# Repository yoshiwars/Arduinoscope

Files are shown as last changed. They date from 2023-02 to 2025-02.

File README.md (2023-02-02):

# Arduinoscope
My attempt to motorize my 8inch Dobsonian. Works fine with Stellarium. Motors are 27:1 Planetary Gearbox Nema 17s. Go to via bluetooth in Stellarium and object tracking is slightly off, probably because the gears and belts are not super high tolerance.

//TODO - Describe Parts List, Circuit diagrams, add photos, etc.

Relies on https://github.com/DavidArmstrong/SiderealPlanets for all the Alt/Az conversion

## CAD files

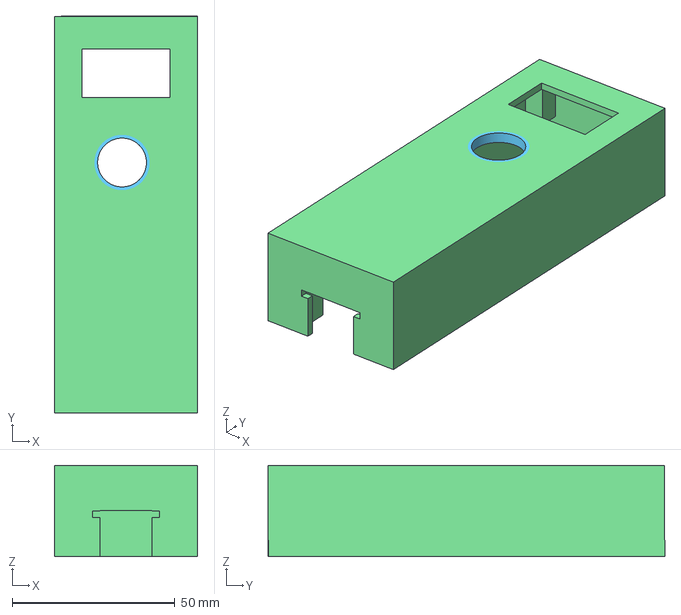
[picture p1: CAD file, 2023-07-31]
3D Print Files/Binoculurs/Handheld-Top.3mf
44.0 x 122.0 x 28.0 mm

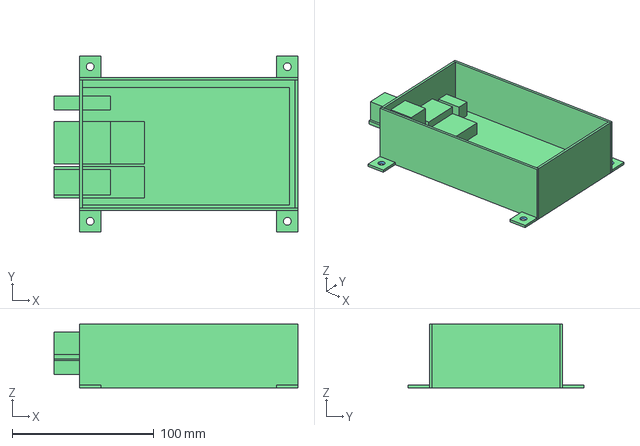
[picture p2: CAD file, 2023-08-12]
3D Print Files/Designs/Case for Telescope with focuser.3mf
172.0 x 124.0 x 45.0 mm

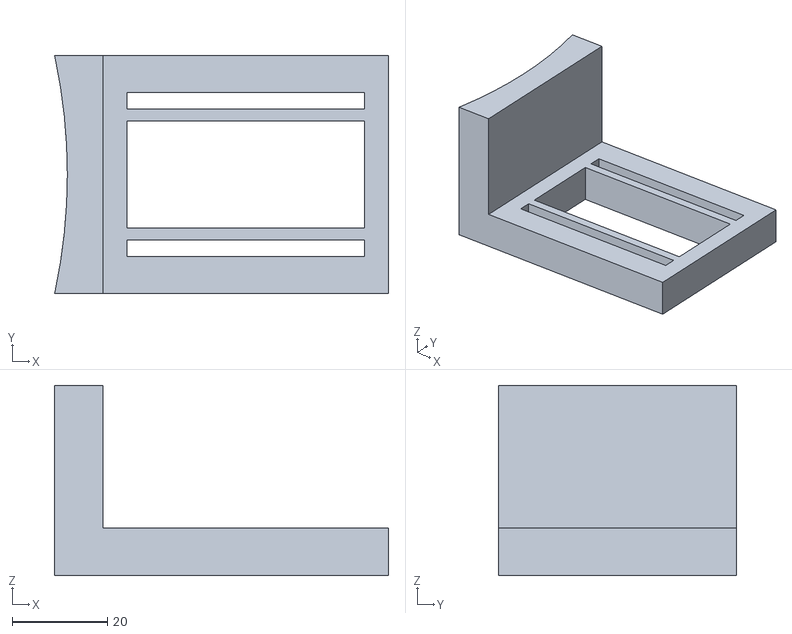
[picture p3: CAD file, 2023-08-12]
3D Print Files/STL/focuser mount.stl
70.2 x 50.0 x 40.0

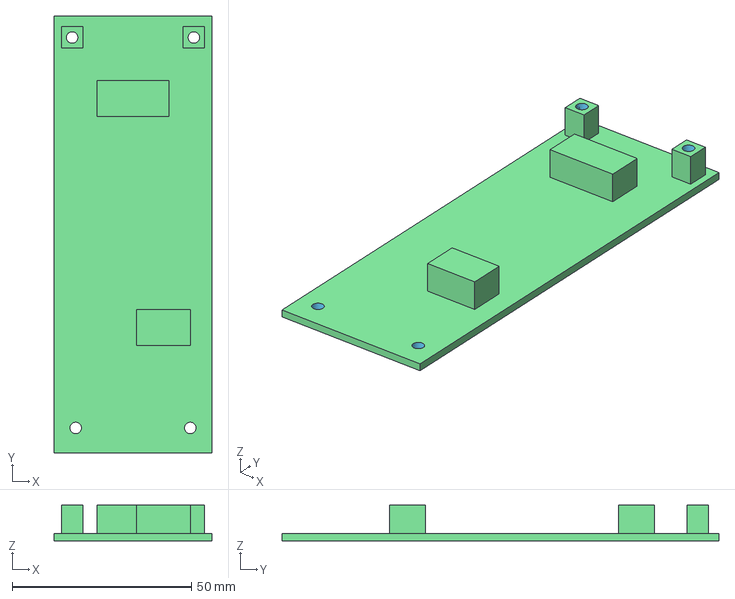
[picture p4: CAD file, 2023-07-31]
3D Print Files/Binoculurs/Handheld-Bottom.3mf
44.0 x 122.0 x 10.0 mm

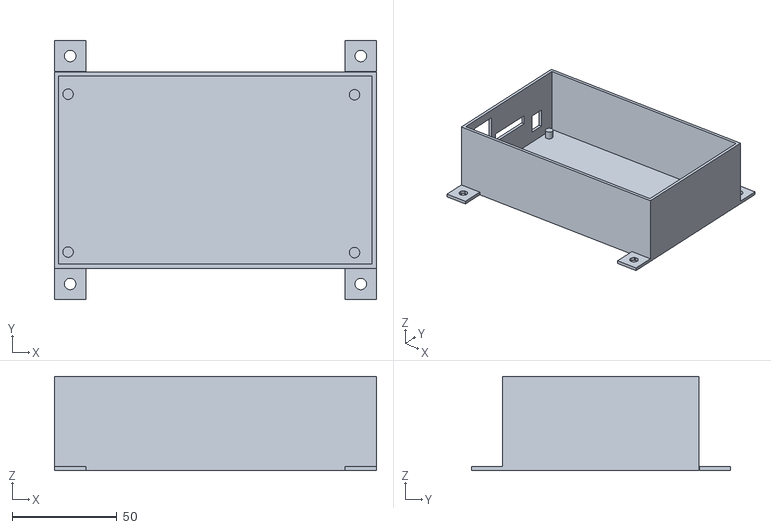
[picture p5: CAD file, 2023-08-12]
3D Print Files/STL/Case for Telescope with focuser.stl
154.0 x 124.0 x 45.0

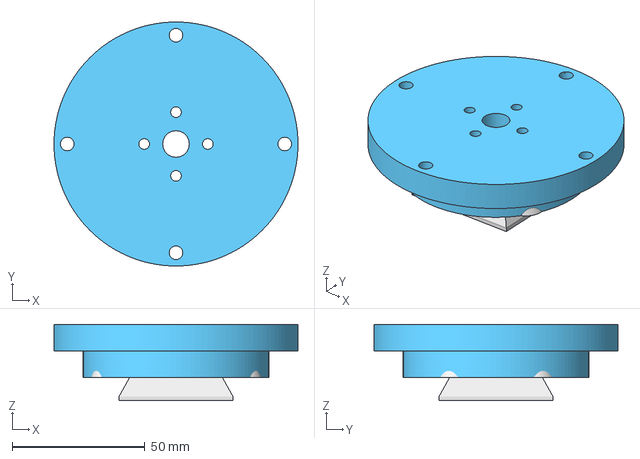
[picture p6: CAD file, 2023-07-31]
3D Print Files/Binoculurs/Bottom.3mf
92.0 x 92.0 x 28.7 mm

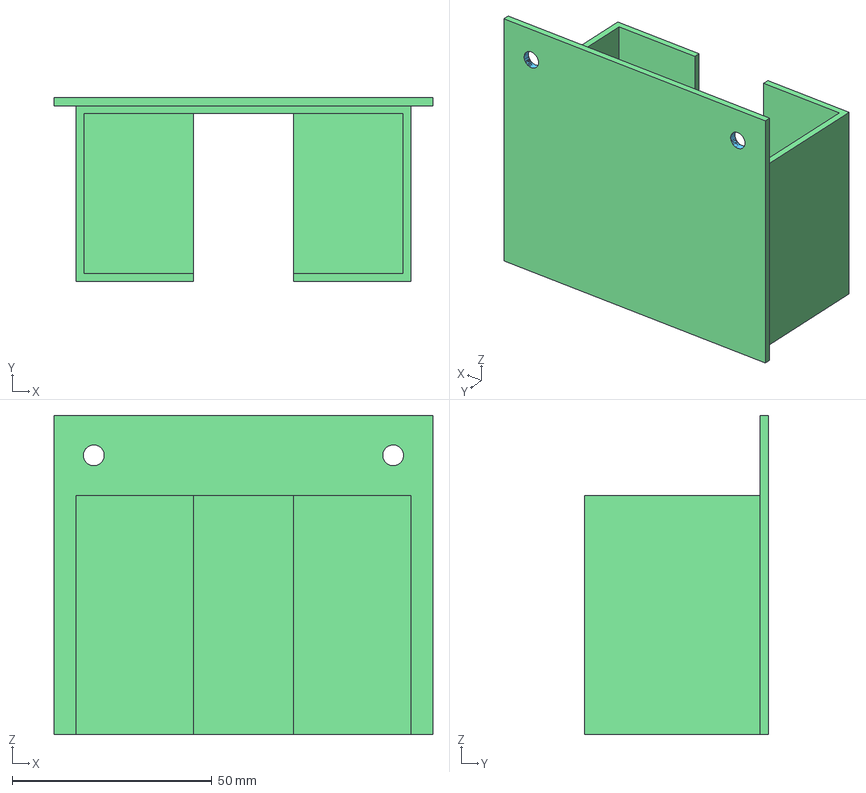
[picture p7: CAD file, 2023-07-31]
3D Print Files/Designs/BatteryHolder.3mf
95.0 x 46.0 x 80.0 mm

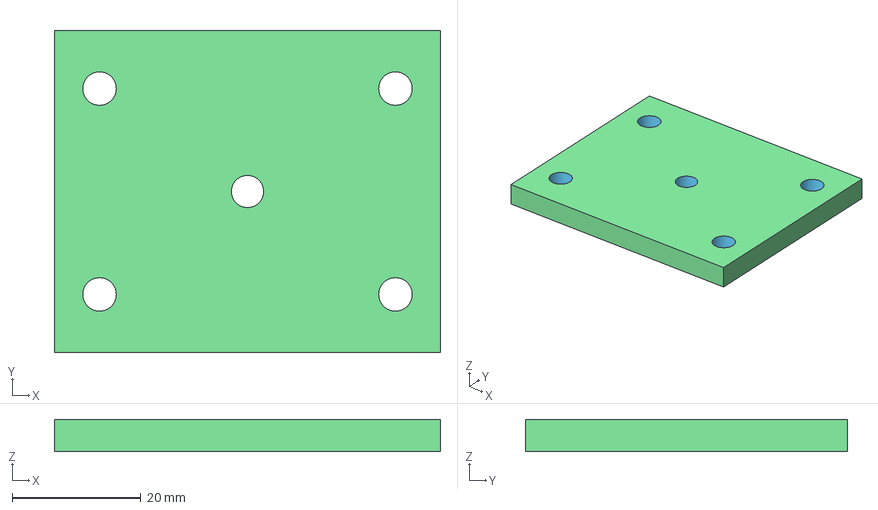
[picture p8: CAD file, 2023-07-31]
3D Print Files/Binoculurs/CameraMountPlate.3mf
60.0 x 50.0 x 5.00 mm

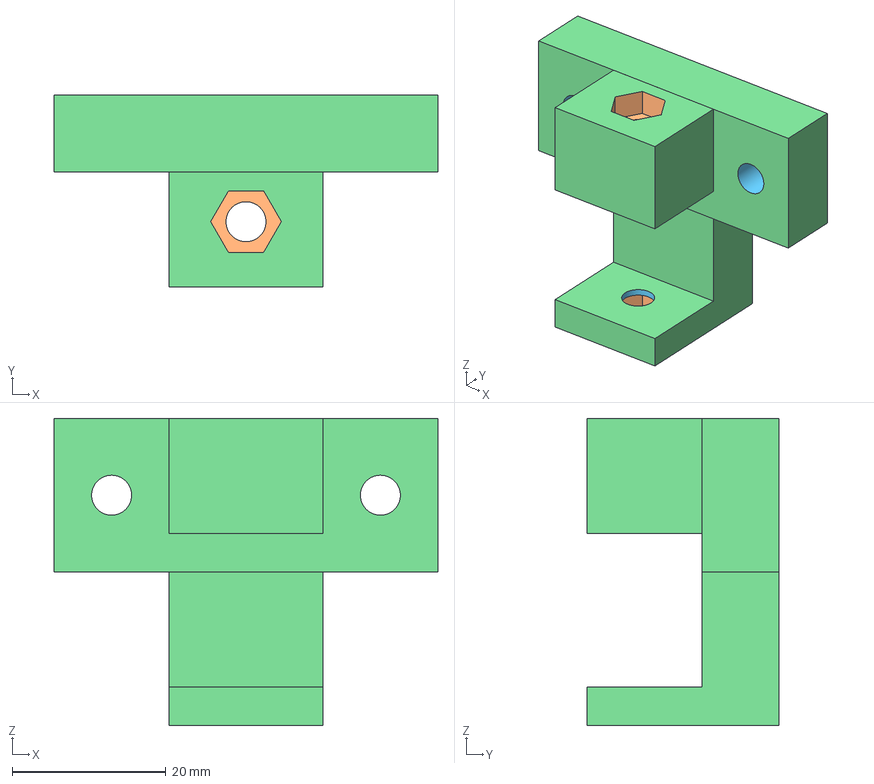
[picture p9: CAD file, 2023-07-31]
3D Print Files/Designs/Tensioner.3mf
50.0 x 25.0 x 40.0 mm

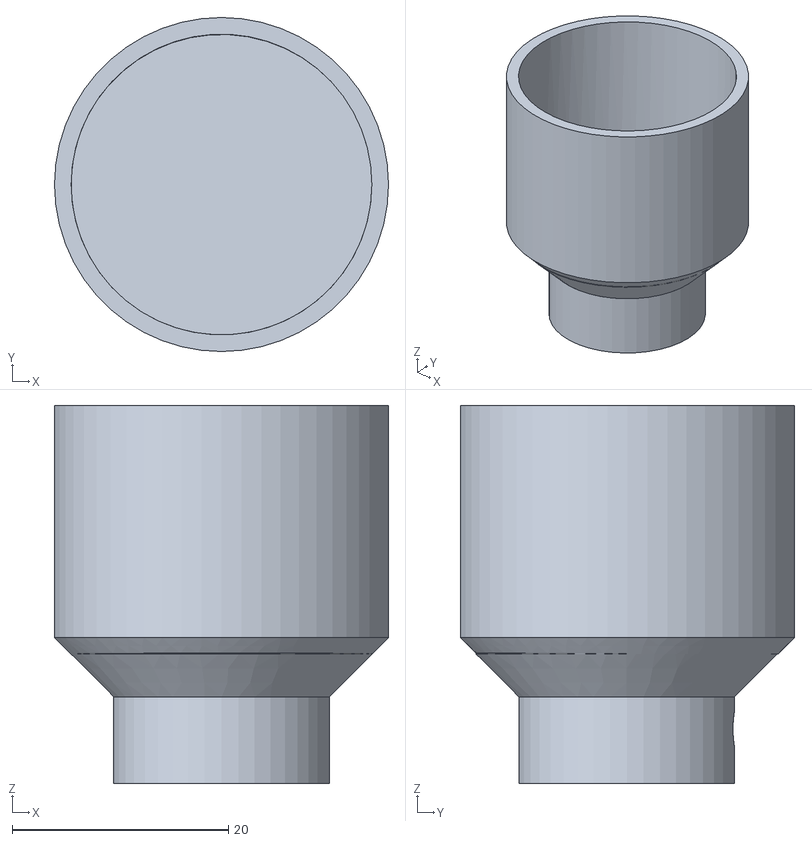
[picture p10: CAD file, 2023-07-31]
3D Print Files/STL/Focus socket-Cut002.stl
30.9 x 30.9 x 35.0

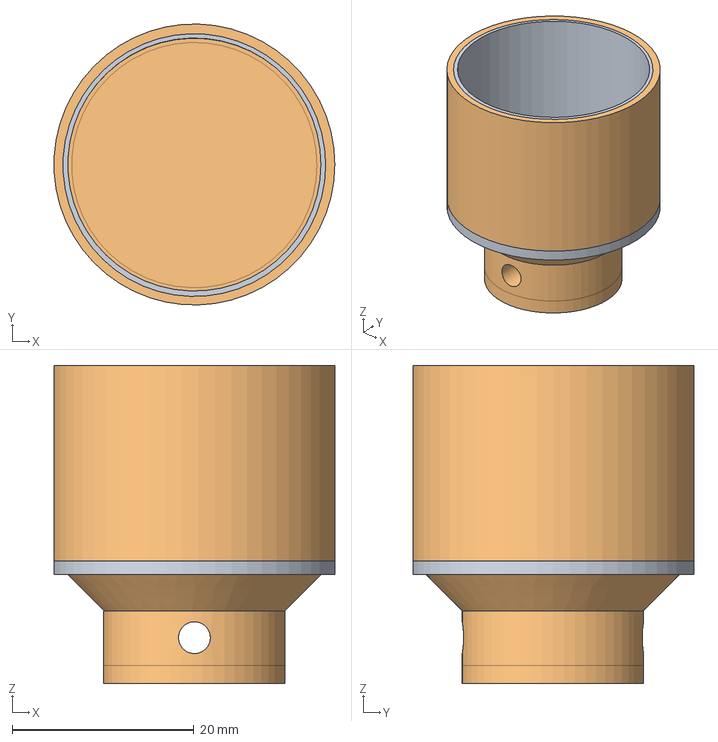
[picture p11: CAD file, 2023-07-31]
3D Print Files/Designs/Focus socket.FCStd
30.9 x 30.9 x 35.0 mm

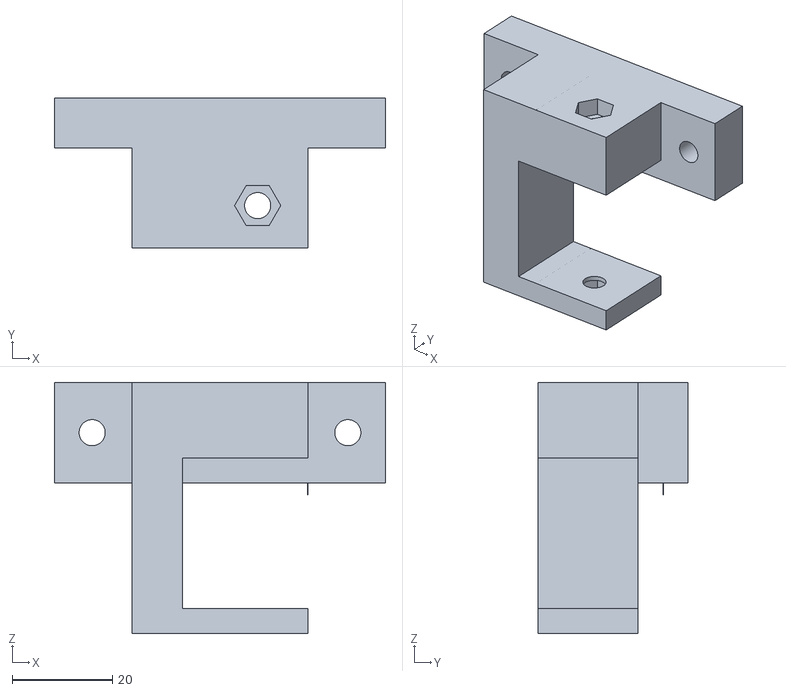
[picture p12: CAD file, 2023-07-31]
3D Print Files/STL/Tensioner.stl
65.9 x 30.0 x 50.0

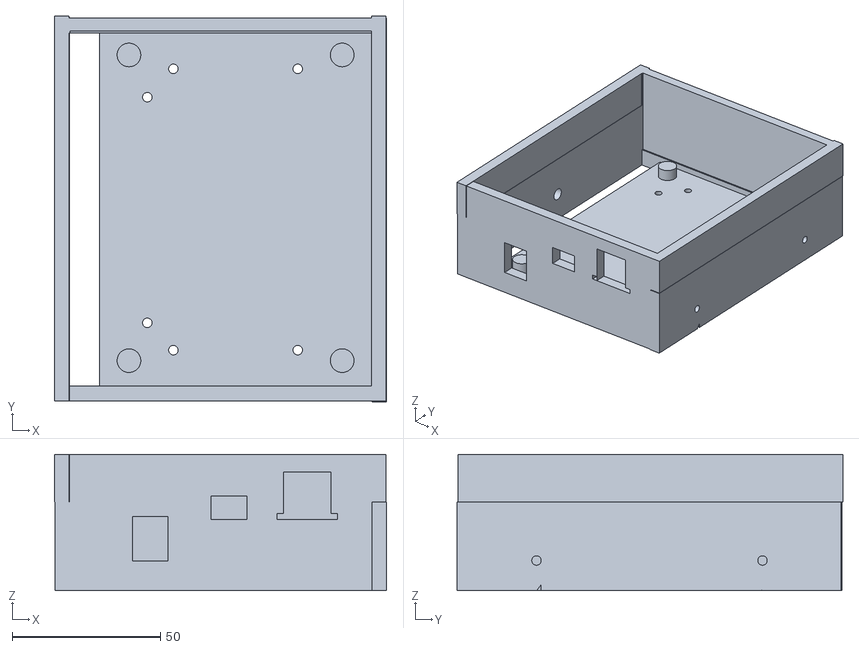
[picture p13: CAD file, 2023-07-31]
3D Print Files/Binoculurs/Motor and Board Holder.stl
112.2 x 130.3 x 46.0

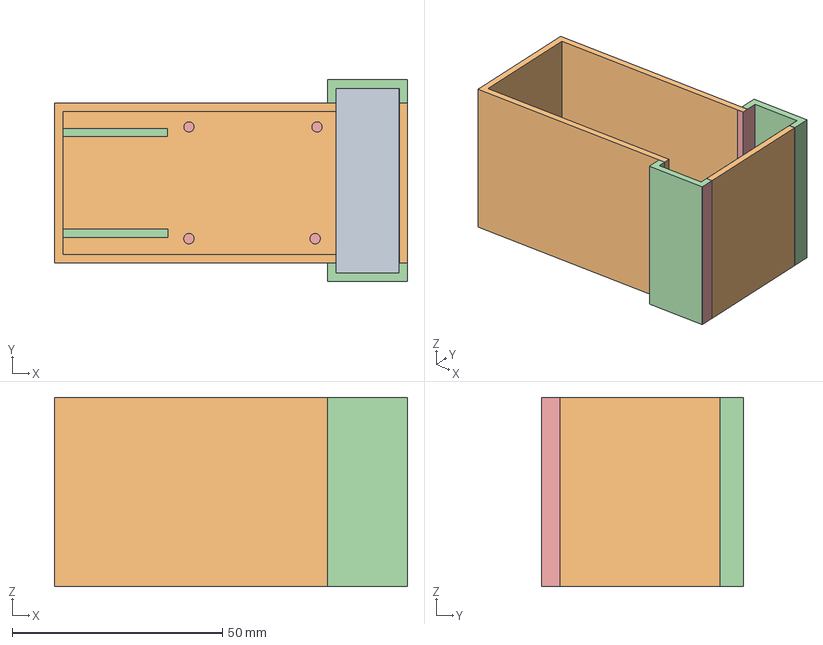
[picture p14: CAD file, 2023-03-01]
3D Print Files/Designs/MotorFocuser.FCStd
84.0 x 48.1 x 45.0 mm

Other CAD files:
3D Print Files/Designs/focuser mount.3mf
3D Print Files/STL/BatteryHolder.stl
3D Print Files/STL/Focus socket-Cut.stl
3D Print Files/Binoculurs/Box.stl
3D Print Files/Binoculurs/AxisSpacer.3mf
3D Print Files/Binoculurs/AxisSpacer.stl
3D Print Files/Binoculurs/AxisSpacerCut.stl
3D Print Files/Binoculurs/Bottom.stl
3D Print Files/Binoculurs/CameraMountPlate.stl
3D Print Files/Binoculurs/CameraMountSpacer.3mf
3D Print Files/Binoculurs/CameraMountSpacer.stl
3D Print Files/Binoculurs/Handheld-Bottom.stl
3D Print Files/Binoculurs/Handheld-Top.stl
3D Print Files/Binoculurs/Handheld.3mf
3D Print Files/Binoculurs/Motor and Board Bottom.3mf
3D Print Files/Binoculurs/Motor and Board Mount.3mf
3D Print Files/Binoculurs/Motor and Board Mount.stl
3D Print Files/Binoculurs/ScreenHolder.stl
3D Print Files/Binoculurs/StorageBox.3mf
3D Print Files/Binoculurs/StorageBox.stl
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

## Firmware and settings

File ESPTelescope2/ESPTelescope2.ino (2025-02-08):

#include "lcdgfx.h"
#include "lcdgfx_gui.h"
#include <AccelStepper.h>
#include <TinyGPSPlus.h>
#include <SiderealPlanets.h>
#include "BluetoothSerial.h"
#include <TimeLib.h>
#include "Preferences.h"
#include <SiderealObjects.h>
#include <ESP32Encoder.h>
#include <esp_now.h>
#include <WiFi.h>

/************************************************************************************************************************
Start Configurable Items 
*************************************************************************************************************************/
#define MOUNT_NAME "StarMax90"                    //Name of the Mount - Bluetooth Name etc.
#define FIRMWARE_VERSION "0.3"                     //Just for Informational Purposes
#define FIRMWARE_DATE "NOV 05 2024"                //Just for Informational Purposes
#define FIRMWARE_TIME "23:15:00"

//this is expecting the Alt and Az gearing to be the same. Will separate this at some point
const int GEAR_RATIO = 15;                       //where 1 is no gearing (ex. 300 Tooth gear / 20 tooth gear = 15), 15 Telescope, 1 Binoc
const double SINGLE_STEP_DEGREE =  360.0 / 200.0;    // the motor has 200 regular steps for 360 degrees (360 divided by 200 = 1.8)
const double MOTOR_GEAR_BOX = 26 + (103.0/121.0);                 //where 1 is no gearing (26 + (103/121)) planetary gearbox version
const float MAX_MOTOR_SPEED = 3000;              //250 is probably good without GEAR_RATIO >1, 1500 Telescope, 250 Binoc 

//Define Motor setup
const int ALT_DIRECTION_PIN = 13;                 //ALT Driver Dir
const int ALT_STEP_PIN = 12;                      //ALT Driver Step
const int AZ_DIRECTION_PIN = 27;                 //AZ Driver Dir
const int AZ_STEP_PIN = 14;                      //AZ Driver Step
const int MOTOR_INTERFACE_TYPE = 1;             //AccelStepper Motor Type 1
//#define MIN_PULSE_WIDTH 50                      //use to adjust stepper pulses, comment out for default

//Define Remote setup
const int Y_JOYSTICK_PIN = 35;                  //Up/Down Pin on the Remote
const int Y_INVERT = 1;                         //1 is normal, -1 inverted , binoc -1, telescope 1
const int X_JOYSTICK_PIN = 34;                  //Left/Right Pin on the remote
const int X_INVERT = 1;                        //1 is normal, -1 inverted , binoc -1, telescope 1

const int BUTTON_PIN = 39;                      //button on Remotes
const int ANALOG_READ_RESOLUTION = 4095;        //ESP32 has this resolution, other chips may vary

//Define Encoders
const int AZ_ENCODER_1 = 25;
const int AZ_ENCODER_2 = 26;
const double AZ_ENCODER_GEAR = 15;                //300 / 20
const double AZ_ENCODER_DEGREE_PER_STEP = 0.15;   //360 / (600 * 4)
const int AZ_ENCODER_INVERT = -1;                 //change the direction of the Encoder when adding to currentAz
const int ALT_ENCODER_1 = 32;
const int ALT_ENCODER_2 = 33;
const double ALT_ENCODER_GEAR = 15;               //300 / 20
const double ALT_ENCODER_DEGREE_PER_STEP = 0.15;  //360 / (600 * 4)
const int ALT_ENCODER_INVERT = -1;                //change the direction of the Encoder when adding to currentAlt
#define ENCODERFILTER                             //If moving too fast, need to lower the debounce to 0. Comment out at slower speeds.

//Comment Out HAS_FOCUSER for no Focuser
#define HAS_FOCUSER

#ifdef HAS_FOCUSER
  const int FOCUS_DIRECTION_PIN = 4;            //Focus Driver Dir
  const int FOCUS_STEP_PIN = 5;                 //Focus Driver Step
  const int MAX_FOCUS_SPEED = 1024;
  const int FOCUS_INTERFACE_TYPE = 1;           //1 is with driver DRV8825
#endif

//Shift Register for motor speeds
const int LATCH_PIN = 19;                       //Pin connected to ST_CP of 74HC595
const int CLOCK_PIN = 18;                       //Pin connected to SH_CP of 74HC595
const int DATA_PIN = 23;                         //Pin connected to DS of 74HC595

//Receiver
uint8_t receiverAddress[] = {0xa0, 0xb7, 0x65, 0x64, 0x29, 0x7c};


//uncomment to get debugging
//#define DEBUG
//#define DEBUG_STEPS
//#define DEBUG_X_JOYSTICK
//#define DEBUG_Y_JOYSTICK 
//#define DEBUG_GPS
//#define DEBUG_COMMS
//#define DEBUG_ENCODER
/************************************************************************************************************************
End Configurable Items
*************************************************************************************************************************/

/************************************************************************************************************************
Global Variables - These should not need to change based on devices
*************************************************************************************************************************/

BluetoothSerial btComm;       //Bluetooth Setup
SiderealPlanets myAstro;      //Used for calculations
SiderealObjects myObjects;    //Used for GoTo Functions
Preferences preferences;      //Stores persistent variables

//button states
int buttonState = LOW;                // the current reading from the input pin
int lastButtonState = LOW;            // the previous reading from the input pin
unsigned long lastDebounceTime = 0;   // the last time the output pin was toggled
unsigned long debounceDelay = 50;     // the debounce time; increase if the output flickers
unsigned long longPressTime = 500;
bool longYPressActive = false;
bool longXPressActive = false;

//AltAZ motor rotation min
const double rotationDegrees = (SINGLE_STEP_DEGREE / MOTOR_GEAR_BOX); //degrees / single step per rev / gearbox

//Motor Starts
AccelStepper yStepper = AccelStepper(MOTOR_INTERFACE_TYPE,ALT_STEP_PIN,ALT_DIRECTION_PIN);
AccelStepper xStepper = AccelStepper(MOTOR_INTERFACE_TYPE,AZ_STEP_PIN,AZ_DIRECTION_PIN);
#ifdef HAS_FOCUSER
AccelStepper focuser = AccelStepper(FOCUS_INTERFACE_TYPE,FOCUS_STEP_PIN,FOCUS_DIRECTION_PIN);
#endif


ESP32Encoder altEncoder;
ESP32Encoder azEncoder;


float xSpeed = 0;
float ySpeed = 0;
float fSpeed = 0;
float fSpeedSerial = MAX_FOCUS_SPEED;
float realXSpeed = 0;
float realYSpeed = 0;
float realFSpeed = 0;

int stepperSpeed = 3;
int lastStepperSpeed = 0;
int preTrackStepperSpeed = 3;
int stepperDivider = 1;

//Menu Control
unsigned int screenMode = 0;
/*
  0 - GPS Screen
  1 - Main Menu
  2 - Slew Mode
  3 - Settings Menu
  4 - Alignment Screen
      0 - Sync 1st Object
      1 - Sync 2nd Object
      2 - Sync 3rd Object
      3 - Confirm sync
  5 - Offsets Menu
  6 - Goto Menu
  7 - Planets Menu --Not in use anymore
  8 - Target Below Horizon
*/
unsigned int returnScreenMode = 0;
const char *mainMenuItems[] = 
{
  "Move:  Disabled",
  #ifdef HAS_FOCUSER
  "Focus: Disabled",
  #endif
  "Speed: Fast",
  "Settings",
  "Info",
  "GoTo"
};

unsigned int speedIndex = 1;

const char *settingsMenuItems[] = 
{
  "<-- Back",
  "Alignment",
  "Offsets",
  "Tracking: Enabled"
};

const char *alignmentMenuItems[] =
{
  "Move:  Disabled",
  "Speed: Fast",
  "Cancel Alignment"
};

const char *offSetsMenuItems[] =
{
  "<-- Back",
  "Alt:",
  "Az: ",
  "Reset to Default"
};

const char *gotoMenuItems[] =
{
  "<-- Back",
  "Planet: Mercury",
  "Messier: M1",
  "Caldwell: 1",
  "The Moon"
};

const char *planets[] =
{
  "Mercury",
  "Venus",
  "Mars",
  "Jupiter",
  "Saturn",
  "Uranus",
  "Neptune"
};

unsigned int messierObject = 1;
unsigned int caldwellObject = 1;
unsigned int planetObject = 0;

LcdGfxMenu mainMenu(mainMenuItems, sizeof(mainMenuItems) / sizeof(char *) );
LcdGfxMenu settingsMenu(settingsMenuItems, sizeof(settingsMenuItems) / sizeof(char *) );
LcdGfxMenu alignmentMenu(alignmentMenuItems, sizeof(alignmentMenuItems) / sizeof(char *) );
LcdGfxMenu offsetsMenu(offSetsMenuItems, sizeof(offSetsMenuItems) / sizeof(char *) );
LcdGfxYesNo alignmentConfirm("Apply new offset?");

LcdGfxMenu gotoMenu(gotoMenuItems, sizeof(gotoMenuItems)/sizeof(char *));

//alignment Variables
int alignmentScreen = 0;

//the following is to hold the incoming sync Alt and the current alt so that they can be compared.
double alignmentAltValues[][2] = {
  {0.0,0.0}, //sync Alt, current alt
  {0.0,0.0},
  {0.0,0.0}
};

double alignmentAzValues[][2] = {
  {0.0,0.0},
  {0.0,0.0},
  {0.0,0.0}
};

double alignmentAltOffset = 0.0;
double alignmentAzOffset = 0.0;

//JoyStick
int lastYState = 0;
int yState = 0;
unsigned long lastYDebounceTime = 0;
unsigned int yDeadZone = 0;
unsigned int xDeadZone = 0;
unsigned int maxY = ANALOG_READ_RESOLUTION;
unsigned int maxX = ANALOG_READ_RESOLUTION;

int lastXState = 0;
int xState = 0;
unsigned long lastXDebounceTime = 0;

bool moving = false;
bool yMoving = false;
bool xMoving = false;

bool focusing = false;

//communication
const byte numChars = 32;
char input[numChars];
char serialInput[numChars];
char output[numChars];
const byte gpsNumChars = 80;
char gpsData[gpsNumChars];
bool newData = false;
bool outData = false;
bool synced = false;


// Structure example to send data
// Must match the receiver structure
typedef struct struct_message {
  char message[numChars];  
} struct_message;

// Create a struct_message called myData
struct_message espNowOut;
struct_message espNowIn;

esp_now_peer_info_t peerInfo;

//Sync Time Variables
int inHourOffset;
int inHour;
int inMinute;
int inSecond;
int inMonth;
int inDay;
int inYear;


//GPS
TinyGPSPlus gps;
bool gpsAcquired = false;
long lastGPSCheck = 0;

float flat = 0;
float flon = 0;
float faltitude;

int sats;

float gpsQueryTime;

//hold the received RA, Dec
int raHH;
int raMM;
int raSS;
int decD;
int decMM;
int decSS;

//Sync coords
double currentAlt = 0;
double currentAz = 0;
double moveOffsets[] = {1.0,1.0};
double tempMoveOffsets[] = {1.0,1.0};

//Target Coords for slewing
int targetRaHH;
int targetRaMM;
int targetRaSS;
int targetDecD;
int targetDecMM;
int targetDecSS;
double targetAlt;
double targetAz;
bool slewComplete = true;
bool tracking = true;
bool isTracking = false;
long slewScreenTimeOut = 2000;
long slewScreenUpdate = 0;

const char *sites[4] = {"","","",""};

DisplaySSD1306_128x64_I2C display(-1); // or (-1,{busId, addr, scl, sda, frequency}). This line is suitable for most platforms by default

void setup() {
  preferences.begin("scope",false);   //start up preferences
  
  if(preferences.isKey("altOffset")){
    moveOffsets[0] = preferences.getDouble("altOffset");
  }

  if(preferences.isKey("azOffset")){
    moveOffsets[1] = preferences.getDouble("azOffset");
  }

  for(int i = 0; i < 4; i++){
    if(preferences.isKey("site" + i)){
      sites[i] = preferences.getString("site" + i).c_str();
    }
  }

  // Set device as a Wi-Fi Station
  WiFi.mode(WIFI_STA);

  // Init ESP-NOW
  if (esp_now_init() != ESP_OK) {
    Serial.println("Error initializing ESP-NOW");
    return;
  }

  // Once ESPNow is successfully Init, we will register for Send CB to
  // get the status of Trasnmitted packet
  esp_now_register_send_cb(OnDataSent);
  
  // Register peer
  memcpy(peerInfo.peer_addr, receiverAddress, 6);
  peerInfo.channel = 0;  
  peerInfo.encrypt = false;
  
  // Add peer        
  if (esp_now_add_peer(&peerInfo) != ESP_OK){
    Serial.println("Failed to add peer");
    return;
  }
  // Register for a callback function that will be called when data is received
  esp_now_register_recv_cb(esp_now_recv_cb_t(OnDataRecv));

  #ifdef HAS_FOCUSER
    speedIndex = 2;
  #endif
  // Set all Pin Modes
  pinMode(Y_JOYSTICK_PIN, INPUT);
  pinMode(X_JOYSTICK_PIN, INPUT);
  pinMode(BUTTON_PIN, INPUT_PULLUP);
  pinMode(LATCH_PIN, OUTPUT);
  pinMode(CLOCK_PIN, OUTPUT);
  pinMode(DATA_PIN, OUTPUT);
    
  //Start Comms
  #ifdef DEBUG
    Serial.begin(115200);   //USB
  #endif
  #ifndef DEBUG
    Serial.begin(9600);     //USB
  #endif


  //ESP32Encoder::useInternalWeakPullResistors = puType::down;
	// Enable the weak pull up resistors
	ESP32Encoder::useInternalWeakPullResistors = puType::up;

  altEncoder.attachFullQuad(ALT_ENCODER_1, ALT_ENCODER_2);
  azEncoder.attachFullQuad(AZ_ENCODER_1,AZ_ENCODER_2);

  #ifdef ENCODERFILTER
      altEncoder.setFilter(0);
      azEncoder.setFilter(0);
  #endif

  altEncoder.clearCount();
  azEncoder.clearCount();


  btComm.begin(MOUNT_NAME);   //Bluetooth
  Serial2.begin(9600);  //start GPS
  
  #ifdef DEBUG
    Serial.println("Start Up");
    Serial.print("Mount Name: ");
    Serial.println(MOUNT_NAME);
  #endif

  #ifdef MIN_PULSE_WIDTH
    xStepper.setMinPulseWidth(MIN_PULSE_WIDTH);
    yStepper.setMinPulseWidth(MIN_PULSE_WIDTH);
  #endif

  #ifdef DEBUG_STEPS
    Serial.print("GEAR_RATIO: ");
    Serial.println(GEAR_RATIO);
    Serial.print("SINGLE_STEP_DEGREE: ");
    printDouble(SINGLE_STEP_DEGREE, 10000);
    Serial.println("");
    Serial.print("MOTOR_GEAR_BOX: ");
    printDouble(MOTOR_GEAR_BOX, 10000);
    Serial.println("");
    Serial.print("MAX_MOTOR_SPEED: ");
    Serial.println(MAX_MOTOR_SPEED);
    Serial.print("rotationDegrees: ");
    printDouble(rotationDegrees,10000);
    Serial.println("");
  #endif
  
  //-8 = PST
  myAstro.begin();
  myAstro.setTimeZone(-8);
  myAstro.rejectDST();

  myObjects.begin();

  #ifdef DEBUG
    Serial.println("Astro Started");
  #endif
  

  //start up screen
  display.setFixedFont( ssd1306xled_font6x8 );
  display.begin();
  display.clear();

  #ifdef DEBUG
    Serial.println("Screen Started");
  #endif

  yDeadZone = getDeadZone(Y_JOYSTICK_PIN);
  xDeadZone = getDeadZone(X_JOYSTICK_PIN);
  maxY = (ANALOG_READ_RESOLUTION + yDeadZone)/2;
  maxX = (ANALOG_READ_RESOLUTION + xDeadZone)/2;

  #ifdef DEBUG
    Serial.println("Joysticks Calibrated");
  #endif

  //set motor max
  yStepper.setMaxSpeed(MAX_MOTOR_SPEED);
  yStepper.setCurrentPosition(0);
  xStepper.setMaxSpeed(MAX_MOTOR_SPEED);
  xStepper.setCurrentPosition(0);
  #ifdef DEBUG
    Serial.println("Motors set");
  #endif

  #ifdef HAS_FOCUSER
    focuser.setMaxSpeed(MAX_FOCUS_SPEED);
  #endif

  //set up and display movement menu
  showInfo();  

  #ifdef DEBUG
    Serial.println("Ready");
  #endif
}

void loop() {
  
  switch (screenMode){
    case 0: //GPS Mode
    {
      infoScreensControl();
      if(millis() - lastGPSCheck > 10000){
        showInfo();
        lastGPSCheck = millis();
      }
      break;
    }        
    case 1: //Main Screen
    {
      movementButtonControl();
      if(!moving && !focusing){
        menuControl();
      }
      if(moving){ //move if in move mode
        readJoystickAndMove();  
      }
      #ifdef HAS_FOCUSER
        if(focusing){ //Focusing Mode
          readJoystickAndFocus(); 
        }
      #endif
      break;
    }      
    case 2: //Slew Mode
    {
      slewMode();
      infoScreensControl();
      break;
    }
    
    case 4: //Alignment
      movementButtonControl();
      if(!moving && !focusing){
        menuControl();
      }
      if(moving){ //move if in move mode
        readJoystickAndMove();  
      }  
      break;
    /*3 - Settings Menu
    5 - OffsetsMenu
    6 - Goto Menu
    7 - Planet Menu
    8 - Target Below Horizon */
    default:
      movementButtonControl();
      menuControl();
      break;
  }

  if(isTracking){
    doTrack();
  }
  
  while (Serial.available() > 0){
    serialCommunication(Serial.read(), 1);
  }
  
  while (btComm.available() > 0){
    serialCommunication(btComm.read(),2);
  }

  while(Serial2.available() > 0){
    if(gps.encode(Serial2.read()))
      getGPS();
  }

  setStepperSpeed();

  accelerateMove();
  #ifdef HAS_FOCUSER
    accelerateFocus();
  #endif

}

#ifdef HAS_FOCUSER
void accelerateFocus(){

  if(abs(realFSpeed - fSpeed)> 1){
    if(realFSpeed < fSpeed){
      realFSpeed++;
    }else if (realFSpeed > fSpeed){
      realFSpeed--;
    }  
  }else{
    realFSpeed = fSpeed;
  }

  #ifdef DEBUG_X_JOYSTICK
    Serial.print("X:");
    Serial.println(realFSpeed);
  #endif
  
  focuser.setSpeed(realFSpeed);
  
  focuser.runSpeed();
  
}
#endif



void accelerateMove(){

  if(abs(realXSpeed - xSpeed)> 1){
    if(realXSpeed < xSpeed){
      realXSpeed++;
    }else if (realXSpeed > xSpeed){
      realXSpeed--;
    }  
  }else{
    realXSpeed = xSpeed;
  }

  if(abs(realYSpeed - ySpeed) > 1){
    if(realYSpeed < ySpeed){
      realYSpeed++;
    }else if(realYSpeed > ySpeed){
      realYSpeed--;
    }  
  }else{
    realYSpeed = ySpeed;
  }

  xStepper.setSpeed(realXSpeed);
  yStepper.setSpeed(realYSpeed);
    
  xStepper.runSpeed();
  yStepper.runSpeed();
}

/*
Communication Output
1 - Serial
2 - btComm
3 - ESPNow
*/
void serialCommunication(byte inByte, int inComm)
{
  
  static unsigned int input_pos = 0;    
  switch(inByte){
    case 0x06:
        output[0] = 'A';
        writeOutput(inComm);
        break;
    case '#':
      serialInput[input_pos] = 0; //terminating null byte
  
      //terminator reached! process newdata
      newData = true;
      
      //reset buffer for next time
      input_pos = 0;    
      break;

    case '\r':   // discard line ends
      break;
    case '\n':
      break;

    default:
     // keep adding if not full ... allow for terminating null byte
    if (input_pos < (numChars - 1))
      serialInput[input_pos++] = inByte;
    break;
  }
  
  if(newData){

    strcpy(input,serialInput);
    processCommunication(inComm);

    for(int i = 0; i < numChars; i++){
      serialInput[i] = '\0';
    }
    newData = false;
  }
}

void processCommunication(int inComm)
{
  String strInput = String(input);
    #ifdef DEBUG_COMMS
      display.printFixed(0,  56, input, STYLE_NORMAL);
      Serial.print("CommType: ");
      Serial.println(inComm);
      Serial.print("Input: ");
      Serial.println(input);
    #endif

    switch (input[1]){
      case 0x06:
        output[0] = 'A';
        writeOutput(inComm);
        break;
      case 'C': //C - Sync Control
        commsSyncControl(input[2], inComm);
        break;
      case 'D': //D - Distance Bars
        commsDistanceBars(inComm);
        break;
      case 'E': //E Commands Not supported
        output[0] = '#';
        writeOutput(inComm);
        break;
      case 'F': //F – Focuser Control
        #ifdef HAS_FOCUSER
          commsFocuserControl(input[2]);
          #endif
        break;
      case 'G': //G – Get Telescope Information
        commsGetTelescopeInfo(inComm);
        break;
      case 'M': //M – Telescope Movement Commands
        commsMovement();
        break;
      case 'Q': //Q – Movement Commands - All Q commands should just stop the telescope.
        setTrack();
        break;
      case 'R': //R – Slew Rate Commands
        commsSlewRate();
        break;
      case 'S': //S – Telescope Set Commands 
        commsSetCommands(strInput, inComm);
        break;
      case 'U': //U - Precision Toggle
        commsPrecisionToggle();
        break;
    }

    for(int i = 0; i < numChars; i++){
      input[i] = '\0';
    }
}

void writeOutput(int comOut){
  #ifdef DEBUG_COMMS
      Serial.print("ComOut: ");
      Serial.println(comOut);
      Serial.print("Output: ");
      Serial.println(output);
    #endif 

    switch(comOut){
      case 1:
        Serial.print(output);
        break;
      case 2:
        btComm.print(output);
        break;
      case 3:
        strcpy(espNowOut.message, output);
        esp_now_send(receiverAddress, (uint8_t *) &espNowOut, sizeof(espNowOut));
        for(int i = 0; i < numChars; i++){
          espNowOut.message[i] = '\0';
        }
        break;
    }
    for(int i = 0; i < numChars; i++){
      output[i] = '\0';
    }
    outData = false;
}
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

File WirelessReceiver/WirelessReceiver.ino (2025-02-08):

#include <esp_now.h>
#include <WiFi.h>

/************************************************************************************************************************
Start Configurable Items 
*************************************************************************************************************************/
//Sender
uint8_t telescopeAddress[] = {0xec, 0x94, 0xcb, 0x6d, 0x0d, 0xcc};
//#define DEBUG_COMMS

/************************************************************************************************************************
End Configurable Items
*************************************************************************************************************************/

/************************************************************************************************************************
Global Variables - These should not need to change based on devices
*************************************************************************************************************************/
const byte numChars = 32;

char input[numChars];

int retries = 0;

esp_now_peer_info_t peerInfo;

// Structure example to send data
// Must match the receiver structure
typedef struct struct_message {
  char message[numChars];  
} struct_message;

// Create a struct_message called myData
struct_message espNowOut;
struct_message espNowIn;

bool newData = false;


void setup() {
  // put your setup code here, to run once:
  Serial.begin(9600);

  // Set device as a Wi-Fi Station
  WiFi.mode(WIFI_STA);

  // Init ESP-NOW
  if (esp_now_init() != ESP_OK) {
    Serial.println("Error initializing ESP-NOW");
    return;
  }

  // Once ESPNow is successfully Init, we will register for Send CB to
  // get the status of Trasnmitted packet
  esp_now_register_send_cb(OnDataSent);
  
  // Register peer
  memcpy(peerInfo.peer_addr, telescopeAddress, 6);
  peerInfo.channel = 0;  
  peerInfo.encrypt = false;
  
  // Add peer        
  if (esp_now_add_peer(&peerInfo) != ESP_OK){
    Serial.println("Failed to add peer");
    return;
  }
  // Register for a callback function that will be called when data is received
  esp_now_register_recv_cb(esp_now_recv_cb_t(OnDataRecv));
}

void loop() {
  // put your main code here, to run repeatedly:
  while (Serial.available() > 0){
    communication(Serial.read());
  }  
}


void communication(byte inByte)
{
  
  static unsigned int input_pos = 0;    
  switch(inByte){
    /*case 6:
      
      break;
      */
    case '\r':   // discard line ends
      break;
    case '\n':
      break;
     case '#':
      
      //terminator reached! process newdata
      if(input_pos > 0){
        newData = true;
      }else{
        break;
      }
      
      //reset buffer for next time
    default:
     // keep adding if not full ... allow for terminating null byte
    if (input_pos < (numChars - 1))
      input[input_pos++] = inByte;
    break;
  }
  
  if(newData){
    
    input[input_pos] = 0; //terminating null byte
    input_pos = 0; 
    strcpy(espNowOut.message, input);

    esp_now_send(telescopeAddress, (uint8_t *) &espNowOut, sizeof(espNowOut));
    for(int i = 0; i < numChars; i++){
      input[i] = '\0';
    }
    newData = false;
  }else if(input_pos == numChars){
    
    #ifdef DEBUG_COMMS
      Serial.print("Input Buffer Overrun: ");
      Serial.print(input);
    #endif
    for(int i = 0; i < numChars; i++){
      input[i] = '\0';
    }
  }
}

// Callback when data is sent through ESPNow
void OnDataSent(const uint8_t *mac_addr, esp_now_send_status_t status) {
  #ifdef DEBUG_COMMS
    Serial.println(status == ESP_NOW_SEND_SUCCESS ? "Delivery Success" : "Delivery Fail");
  #endif

  if(status == ESP_NOW_SEND_SUCCESS){
    for(int i = 0; i < numChars; i++){
      espNowOut.message[i] = '\0';
    }
    retries = 0;
  }else{
    
    if(retries < 3){
      esp_now_send(telescopeAddress, (uint8_t *) &espNowOut, sizeof(espNowOut));
    }
    retries++;
  }
  
}

// Callback when data is received through ESPNow
void OnDataRecv(const uint8_t * mac, const uint8_t *incomingData, int len) {
  memcpy(&espNowIn, incomingData, sizeof(espNowIn));
  #ifdef DEBUG_COMMS
    Serial.println(len);
  #endif
  
  
  Serial.print(espNowIn.message);
  

  for(int i = 0; i < numChars; i++){
      espNowIn.message[i] = '\0';
    }
}

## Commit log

2023-02-02 Adding STLs
    [1.25 Inch Lens Holder Bottom.stl, 1.25 Inch Lens Holder Top.stl, 2 inch Lens Holder Bottom.stl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]
2023-02-02 added Editable files for the stuff I still have.
    [Alt Gear.stl, BottomGear.FCStd, Telescope Holder.FCStd]
2023-02-09 Added Fudge factor
    Added fudge factor to dial in the movement. Its close but not perfect. Maybe need to tighten belts?
    [ESPTelescope2.ino]
2023-03-01 Added Focuser
    [MotorFocuser-Fusion.stl, MotorFocuser.FCStd]
2023-07-31 Reorganized the code to have all the necessary parameters up front.
    Also included design files. Some are not really used.
    [AxisSpacer.3mf, AxisSpacer.stl, AxisSpacerCut.stl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]
2023-08-12 Added Messier Goto
    [Case for Telescope with focuser.3mf, Case for Telescope with focuser.stl, focuser mount.3mf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]
2024-01-12 Trigger change for SonarCloud
2024-09-26 Changes to board 0.3
2024-09-28 switching to TimeLib for time functions.
    so that I don't rely on the GPS
2024-11-08 Adding Wireless Serial Receiver
2024-11-29 Fixed # sending at the beginning
    [ESPTelescope2.ino, WirelessReceiver.ino]
